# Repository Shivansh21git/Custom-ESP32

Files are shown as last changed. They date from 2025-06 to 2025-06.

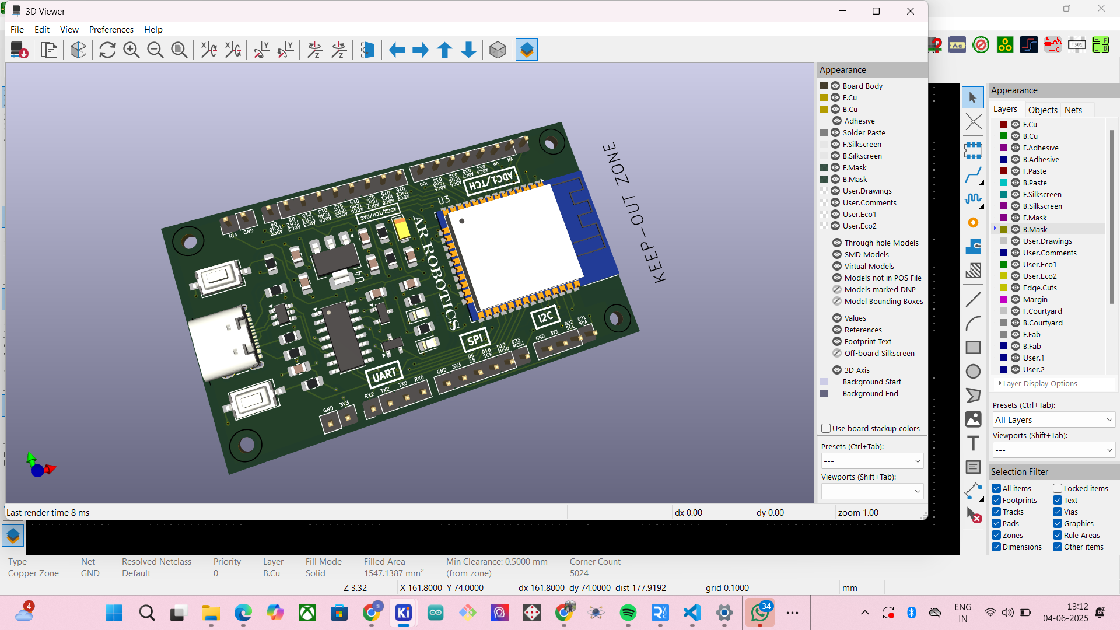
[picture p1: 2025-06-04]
Screenshot (103).png

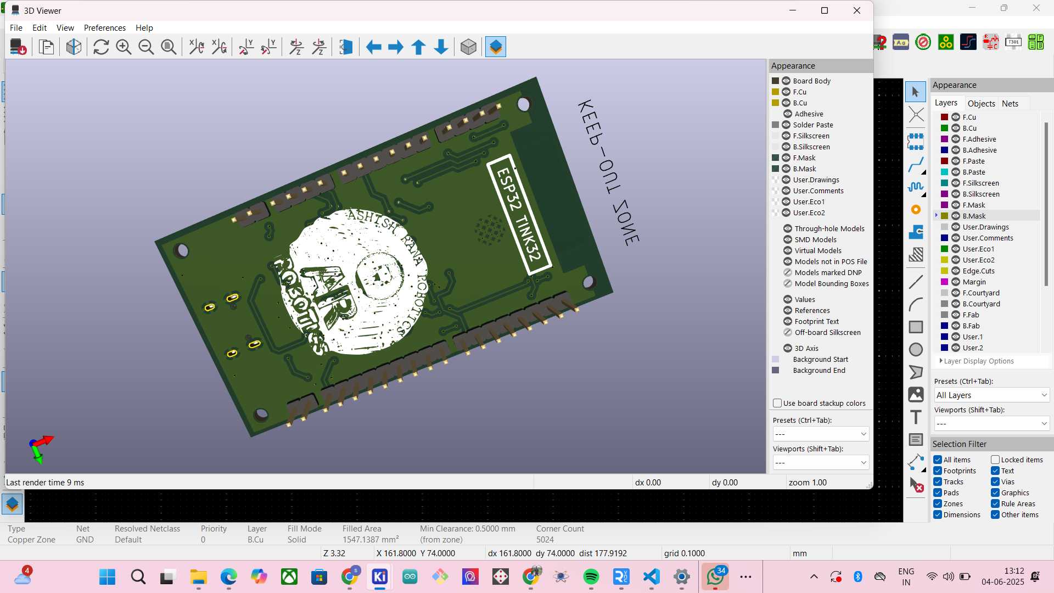
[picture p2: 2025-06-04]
Screenshot (104).png

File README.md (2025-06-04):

# 🚀 Custom ESP32 Development Board – Designed in KiCad

Welcome to the hardware design repo of a **fully custom ESP32-WROOM-32 development board**, engineered for rapid prototyping, compact integration, and modern embedded applications. Designed from the ground up using **KiCad**, this board blends functionality, minimalism, and scalability in one neat package.

---

## ✨ Key Features

- 🔌 **USB Type-C** interface with ESD protection and auto-reset
- 📡 **ESP32-WROOM-32** SoC (Wi-Fi + BLE, dual-core MCU)
- 🔋 **Onboard 3.3V LDO** regulator for stable low-noise operation
- 🎛️ **Accessible I/O headers**: UART, SPI, I2C, ADC, DAC, and GPIOs
- 📐 **Compact PCB layout** – Breadboard compatible
- 🛡️ **Proper antenna clearance & keep-out zone**
- 💾 Designed 100% in **KiCad 7.x**

---

## 🧠 Technical Overview

| Component | Details |
|---|---|
| **MCU** | ESP32-WROOM-32 (ESP32-D0WDQ6) |
| **USB Interface**| USB-C (via CH340/CP2102 + reset circuit) |
| **Power Input**  | 5V via USB-C |
| **Voltage Reg.** | AP2112 / AMS1117-3.3 LDO Regulator |
| **Reset Circuit**| BOOT & EN push buttons with RC logic |
| **Connectivity** | UART, I2C, SPI, ADC, DAC, PWM exposed |
| **Mounting** | 2x M2 screw holes for enclosure compatibility |
| **Board Size** | ~74mm x 32mm |

---

---

## 🛠️ Getting Started

### 🖥️ Open Project
- Clone this repo and open `custom_esp32.kicad_pro` in **KiCad 7.x**

### 🧾 Generate Gerbers
- Go to **File → Plot** → Generate files for your PCB manufacturer

### 🔧 Program the Board
- Use Arduino IDE / ESP-IDF
- Connect via USB-C
- Use `BOOT` + `EN` buttons for flashing if needed

---

## 📦 Fabrication Tips

- Board designed with **antenna clearance**
- Clean **silkscreen labeling** for easy assembly
- No component under USB port for low-profile casing
- Test points can be added if needed for production

---

## 💡 Applications

- IoT Device Development
- Sensor Gateway Nodes
- Home Automation
- Robotics Controller
- Custom Wireless Modules

---

## 🤝 Credits & Contact

Designed by **Shivansh Chauhan**  
📧 Email: `shivanshchauhan.228@gmail.com`  
🔗 LinkedIn: https://www.linkedin.com/in/shivanshchauhan2001

If you like this project, consider giving it a ⭐ on GitHub!

---

> “Great hardware begins with thoughtful design.”

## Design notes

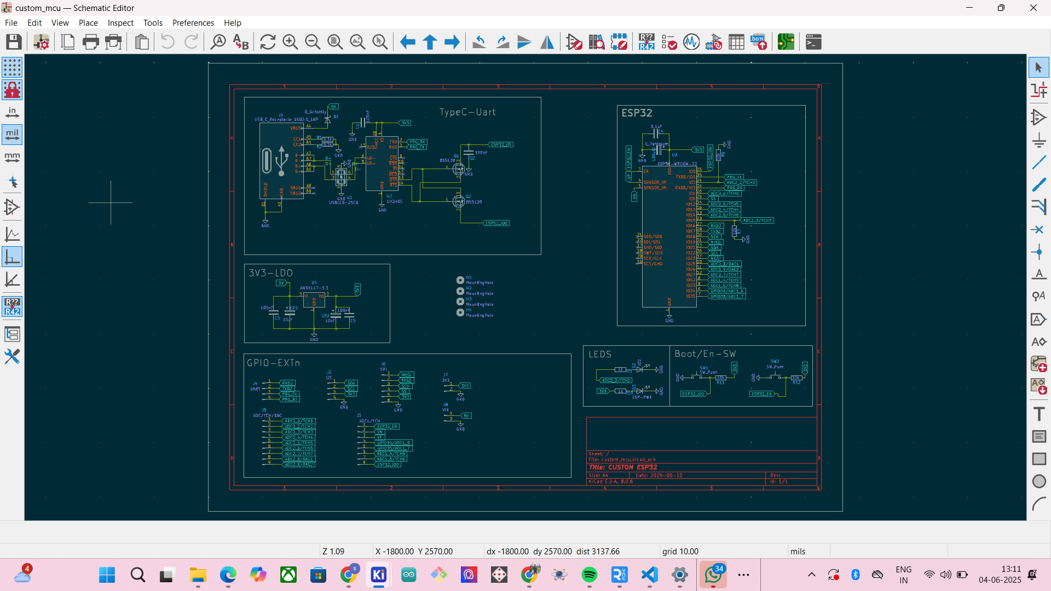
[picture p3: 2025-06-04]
Screenshot (100).png

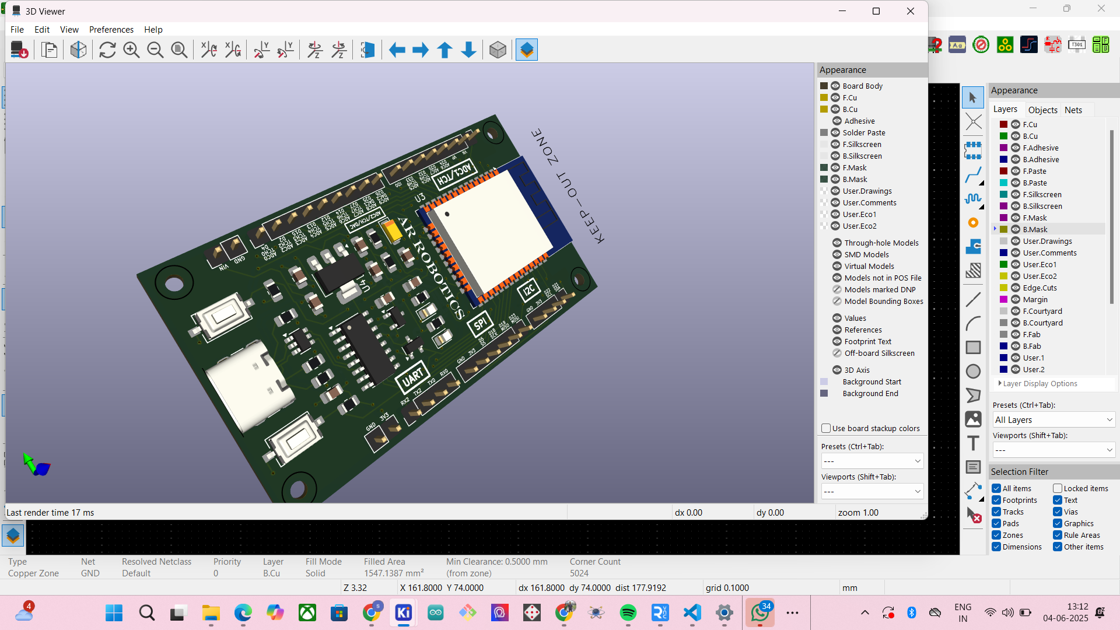
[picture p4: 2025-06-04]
Screenshot (105).png

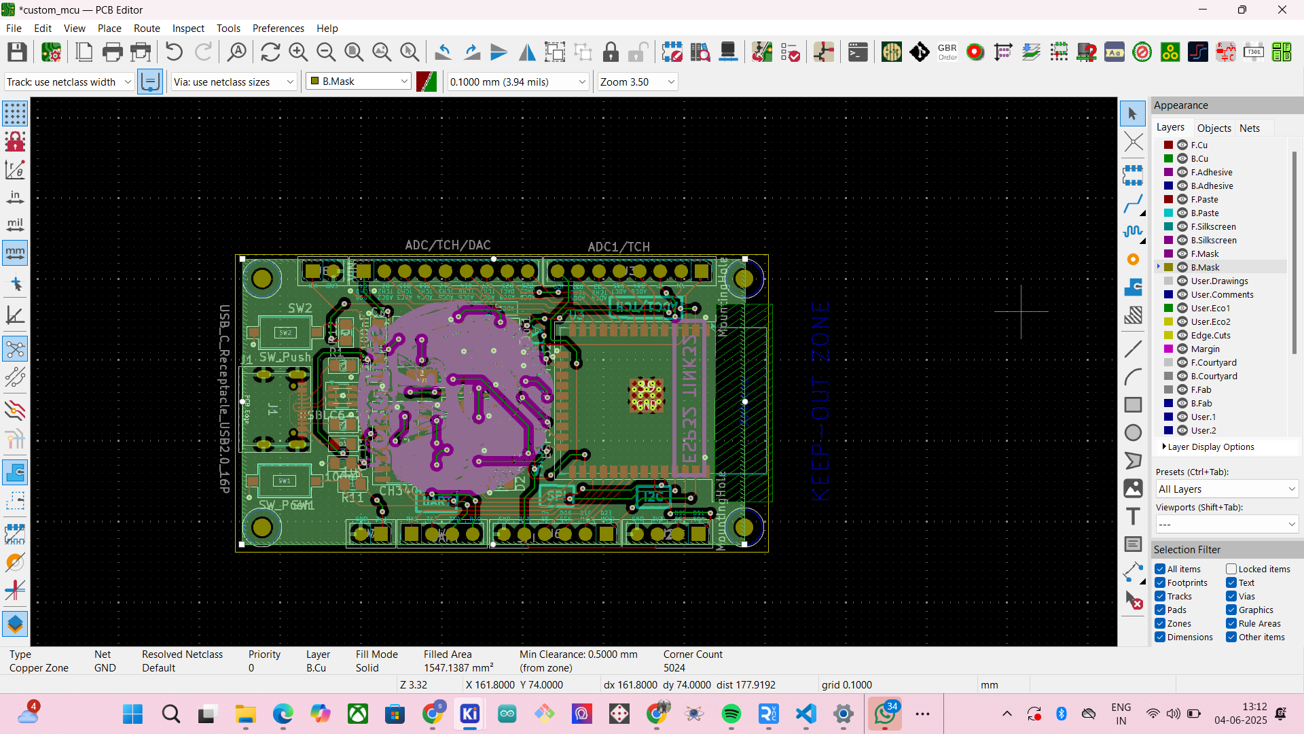
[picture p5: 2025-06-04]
Screenshot (102).png

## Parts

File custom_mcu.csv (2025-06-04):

Id | Designator | Footprint | Quantity | Designation | Supplier and ref
1 | C2,C2,C3,C1 | C_0805_2012Metric_Pad1.18x1.45mm_HandSolder | 4 | 100nF
2 | J4 | PinHeader_1x04_P2.54mm_Vertical | 1 | UART
3 | 100uf1 | CP_EIA-3216-10_Kemet-I | 1 | C_Tantalum
4 | Q2,Q1 | SOT-23 | 2 | BSS138
5 | J1 | USB_C_Receptacle_GCT_USB4105-xx-A_16P_TopMnt_Horizontal | 1 | USB_C_Receptacle_USB2.0_16P
6 | J5 | PinHeader_1x09_P2.54mm_Vertical | 1 | ADC/TCH/DAC
7 | R2,R1 | R_0805_2012Metric_Pad1.20x1.40mm_HandSolder | 2 | 5.1k
8 | C5 | C_0805_2012Metric_Pad1.18x1.45mm_HandSolder | 1 | 100nf
9 | CP1,CP2 | C_0805_2012Metric_Pad1.18x1.45mm_HandSolder | 2 | 10uf
10 | R11,R12,R6,R7 | R_0805_2012Metric_Pad1.20x1.40mm_HandSolder | 4 | 10k
11 | D2 | LED_0805_2012Metric_Pad1.15x1.40mm_HandSolder | 1 | IO2
12 | J7 | PinHeader_1x02_P2.54mm_Vertical | 1 | 3V3
13 | SW1,SW2 | SW_Tactile_SPST_NO_Straight_CK_PTS636Sx25SMTRLFS | 2 | SW_Push
14 | J2 | PinHeader_1x04_P2.54mm_Vertical | 1 | I2C
15 | D1 | R_0805_2012Metric_Pad1.20x1.40mm_HandSolder | 1 | D_Schottky
16 | U4 | SOT-223-3_TabPin2 | 1 | AMS1117-3.3
17 | U1 | SOT-23-6 | 1 | USBLC6-2SC6
18 | J6 | PinHeader_1x06_P2.54mm_Vertical | 1 | SPI
19 | U3 | ESP32-WROOM-32 | 1 | ESP32-WROOM-32
20 | J8 | PinHeader_1x02_P2.54mm_Vertical | 1 | VIN
21 | U2 | SOIC-16_3.9x9.9mm_P1.27mm | 1 | CH340C
22 | J3 | PinHeader_1x08_P2.54mm_Vertical | 1 | ADC1/TCH
23 | R10,R5 | R_0805_2012Metric_Pad1.20x1.40mm_HandSolder | 2 | 1k
24 | D3 | LED_0805_2012Metric_Pad1.15x1.40mm_HandSolder | 1 | ESP-PWR
25 | C4 | C_0805_2012Metric_Pad1.18x1.45mm_HandSolder | 1 | 0.1uF

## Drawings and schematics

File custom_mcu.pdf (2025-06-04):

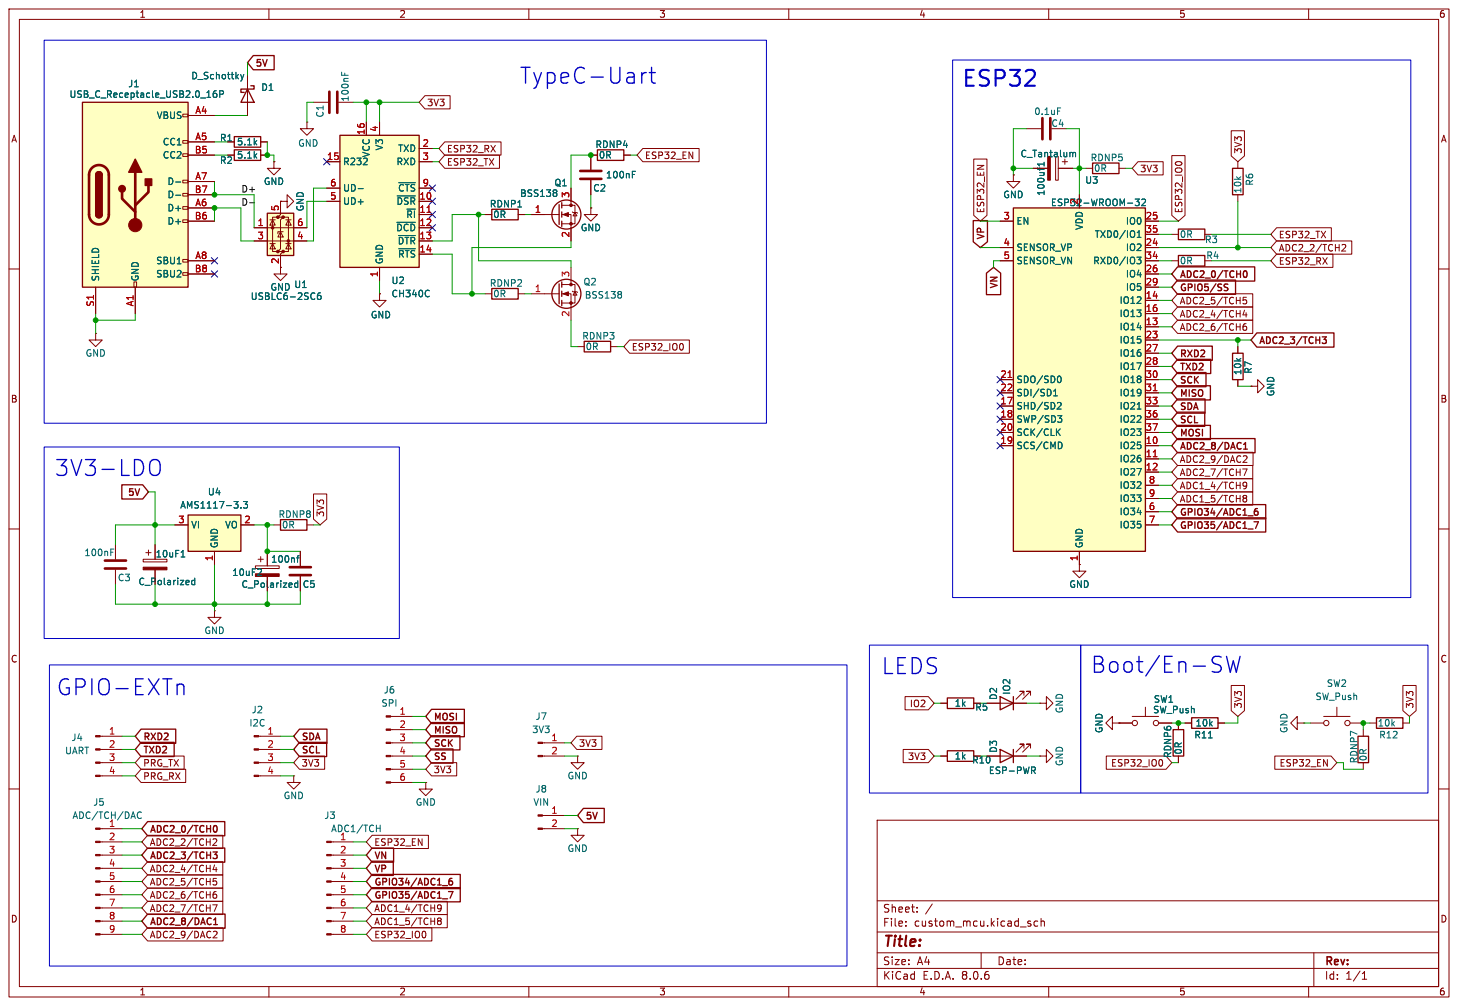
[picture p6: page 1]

1 ~{DSR} 10 ~{RI} 11 ~{DCD} 12 ~{DTR} 13 ~{RTS} 14 R232 15 VCC 16 TXD 2 RXD 3 V3

2 SCK/CLK 20 SDO/SD0 21 SDI/SD1 22

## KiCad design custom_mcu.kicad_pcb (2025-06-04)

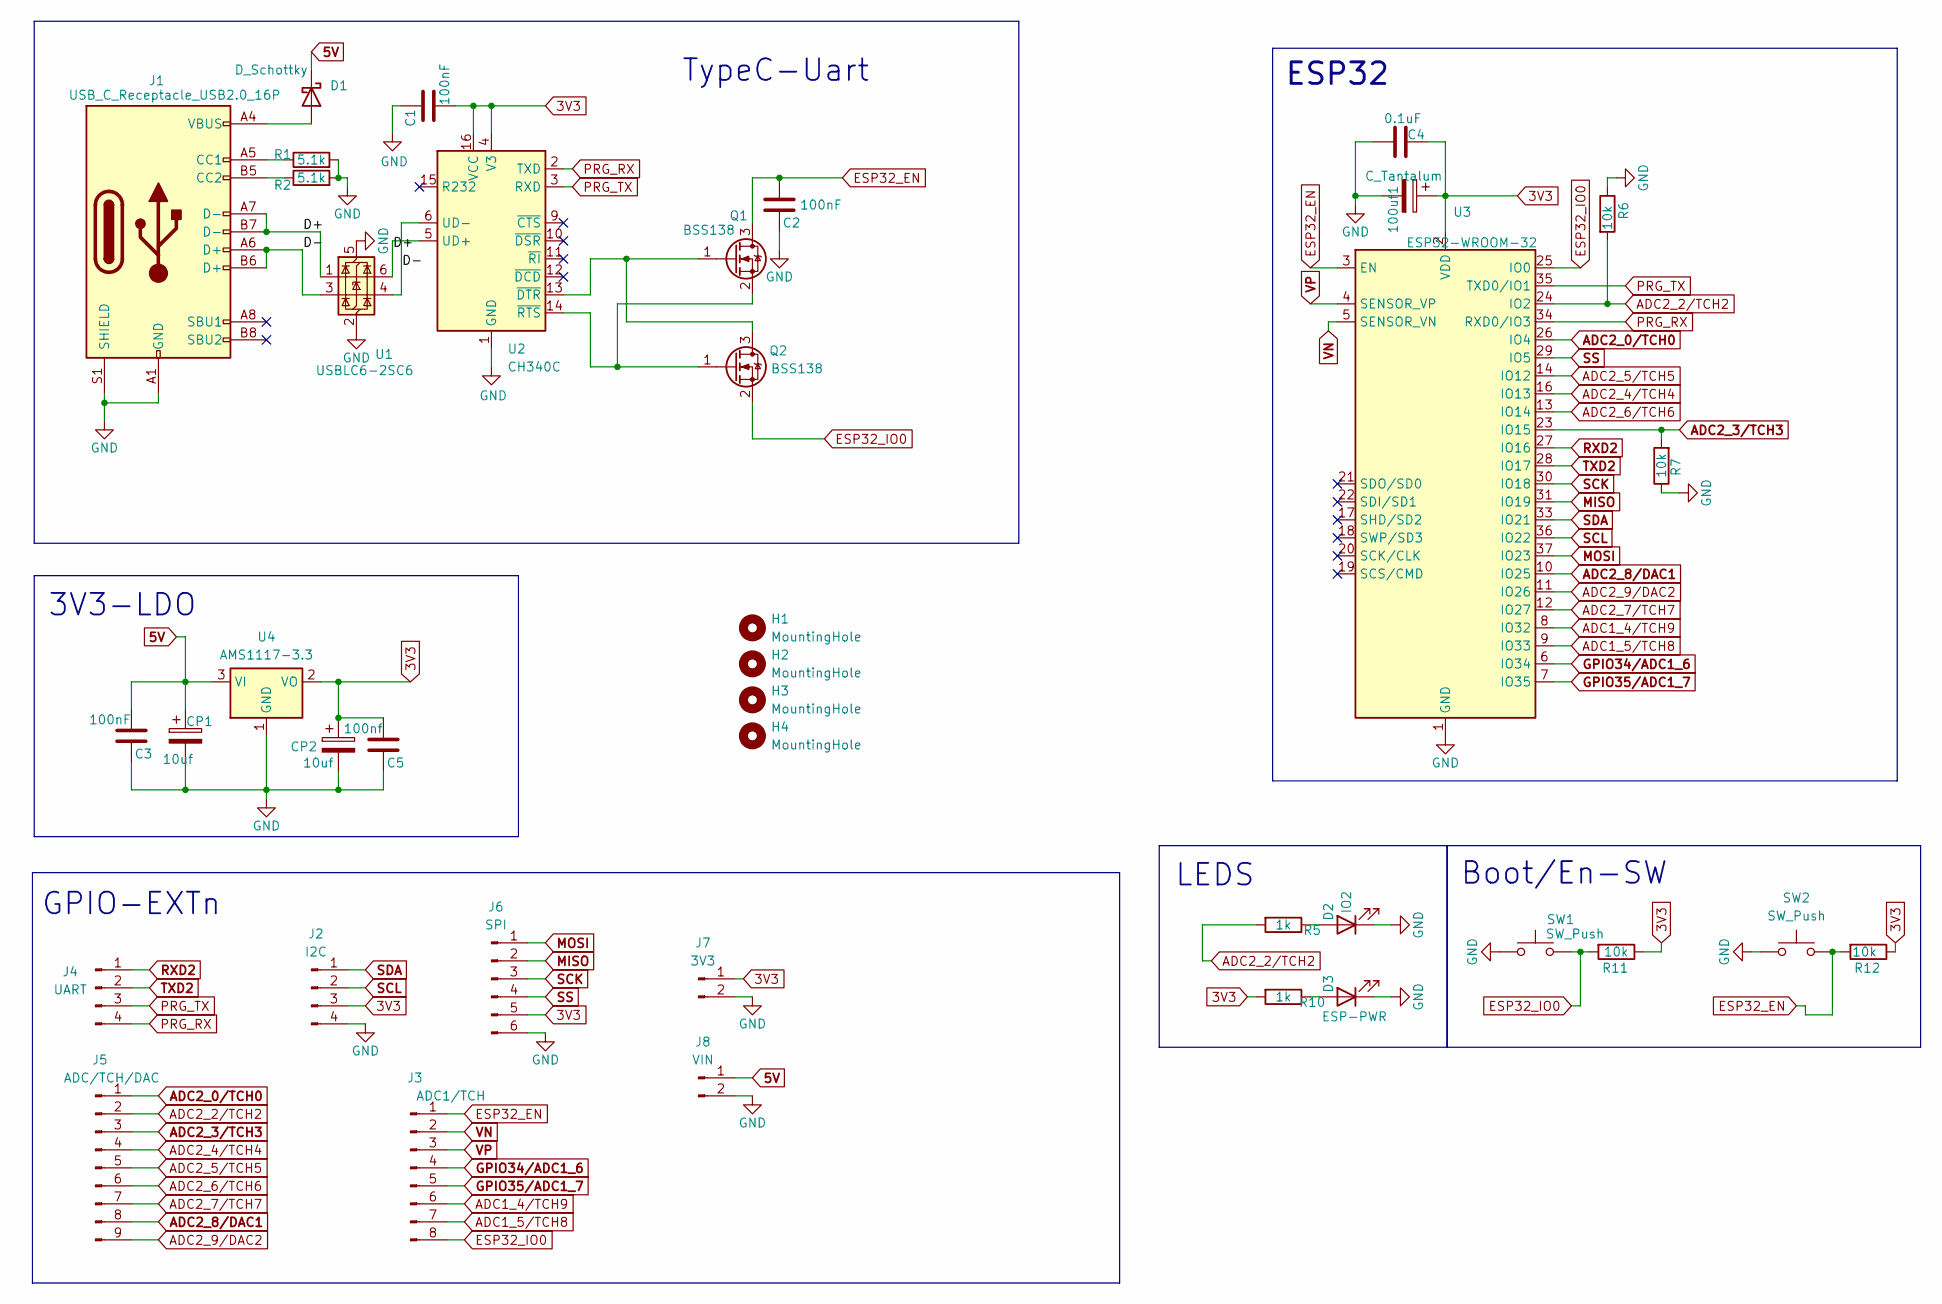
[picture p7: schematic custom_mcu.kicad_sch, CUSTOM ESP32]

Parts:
100uf1: C_Tantalum; CP_EIA-3216-10_Kemet-I
C1, C2, C3: 100nF; C_0805_2012Metric_Pad1.18x1.45mm_HandSolder
C4: 0.1uF; C_0805_2012Metric_Pad1.18x1.45mm_HandSolder
C5: 100nf; C_0805_2012Metric_Pad1.18x1.45mm_HandSolder
CP1, CP2: 10uf; C_0805_2012Metric_Pad1.18x1.45mm_HandSolder
D1: D_Schottky; R_0805_2012Metric_Pad1.20x1.40mm_HandSolder
D2: IO2; LED_0805_2012Metric_Pad1.15x1.40mm_HandSolder
D3: ESP-PWR; LED_0805_2012Metric_Pad1.15x1.40mm_HandSolder
H1, H2, H3, H4: MountingHole; MountingHole_2.2mm_M2
J1: USB_C_Receptacle_USB2.0_16P; USB_C_Receptacle_GCT_USB4105-xx-A_16P_TopMnt_Horizontal
J2: I2C; PinHeader_1x04_P2.54mm_Vertical
J3: ADC1/TCH; PinHeader_1x08_P2.54mm_Vertical
J4: UART; PinHeader_1x04_P2.54mm_Vertical
J5: ADC/TCH/DAC; PinHeader_1x09_P2.54mm_Vertical
J6: SPI; PinHeader_1x06_P2.54mm_Vertical
J7: 3V3; PinHeader_1x02_P2.54mm_Vertical
J8: VIN; PinHeader_1x02_P2.54mm_Vertical
Q1, Q2: BSS138; SOT-23
R1, R2: 5.1k; R_0805_2012Metric_Pad1.20x1.40mm_HandSolder
R5, R10: 1k; R_0805_2012Metric_Pad1.20x1.40mm_HandSolder
R6, R7, R11, R12: 10k; R_0805_2012Metric_Pad1.20x1.40mm_HandSolder
SW1, SW2: SW_Push; SW_Tactile_SPST_NO_Straight_CK_PTS636Sx25SMTRLFS
U1: USBLC6-2SC6; SOT-23-6
U2: CH340C; SOIC-16_3.9x9.9mm_P1.27mm
U3: ESP32-WROOM-32
U4: AMS1117-3.3; SOT-223-3_TabPin2

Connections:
3V3: 100uf1.1, C1.2, C4.2, C5.2, CP2.1, J2.3, J6.5, J7.1, R10.2, R11.1, R12.1, U2.4 (V3), U2.16 (VCC), U3.2 (VDD), U4.2 (VO)
5V: C3.2, CP1.1, D1.1 (K), J8.1, U4.3 (VI)
/D+: J1.A7 (D-), J1.B7 (D-), U1.1 (I/O1), U1.6 (I/O1), U2.5 (UD+)
/D-: J1.A6 (D+), J1.B6 (D+), U1.3 (I/O2), U1.4 (I/O2), U2.6 (UD-)
ADC1_4/TCH9: J3.6, U3.8 (IO32)
ADC1_5/TCH8: J3.7, U3.9 (IO33)
ADC2_0/TCH0: J5.1, U3.26 (IO4)
ADC2_2/TCH2: J5.2, R5.2, R6.2, U3.24 (IO2)
ADC2_3/TCH3: J5.3, R7.2, U3.23 (IO15)
ADC2_4/TCH4: J5.4, U3.16 (IO13)
ADC2_5/TCH5: J5.5, U3.14 (IO12)
ADC2_6/TCH6: J5.6, U3.13 (IO14)
ADC2_7/TCH7: J5.7, U3.12 (IO27)
ADC2_8/DAC1: J5.8, U3.10 (IO25)
ADC2_9/DAC2: J5.9, U3.11 (IO26)
ESP32_EN: C2.2, J3.1, Q1.3 (D), R12.2, SW2.2, U3.3 (EN); also elsewhere on the board
ESP32_IO0: J3.8, Q2.2 (S), R11.2, SW1.2, U3.25 (IO0)
GND: 100uf1.2, C1.1, C2.1, C3.1, C4.1, C5.1, CP1.2, CP2.2, D2.1 (K), D3.1 (K), J1.A1 (GND), J1.A12 (GND), J1.B1 (GND), J1.B12 (GND), J1.S1 (SHIELD), J2.4, J6.6, J7.2, J8.2, R1.2, R2.2, R6.1, R7.1, SW1.1, SW2.1, U1.2 (GND), U1.5 (VBUS), U2.1 (GND), U3.1 (GND), U3.15 (GND), U3.38 (GND), U3.39 (GND), U4.1 (GND); also elsewhere on the board
GPIO34/ADC1_6: J3.4, U3.6 (IO34)
GPIO35/ADC1_7: J3.5, U3.7 (IO35)
MISO: J6.2, U3.31 (IO19)
MOSI: J6.1, U3.37 (IO23)
unnamed: D1.2 (A), J1.A4 (VBUS), J1.A9 (VBUS), J1.B4 (VBUS), J1.B9 (VBUS)
unnamed: D2.2 (A), R5.1
unnamed: D3.2 (A), R10.1
unnamed: J1.A5 (CC1), R1.1
unnamed: J1.B5 (CC2), R2.1
unnamed: Q1.1 (G), Q2.3 (D), U2.13 (~DTR)
unnamed: Q1.2 (S), Q2.1 (G), U2.14 (~RTS)
PRG_RX: J4.4, U2.2 (TXD), U3.34 (RXD0/IO3)
PRG_TX: J4.3, U2.3 (RXD), U3.35 (TXD0/IO1)
RXD2: J4.1, U3.27 (IO16)
SCK: J6.3, U3.30 (IO18)
SCL: J2.2, U3.36 (IO22)
SDA: J2.1, U3.33 (IO21)
SS: J6.4, U3.29 (IO5)
TXD2: J4.2, U3.28 (IO17)
VN: J3.2, U3.5 (SENSOR_VN)
VP: J3.3, U3.4 (SENSOR_VP)

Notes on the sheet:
Boot/En-SW
GPIO-EXTn
3V3-LDO
TypeC-Uart
LEDS
ESP32

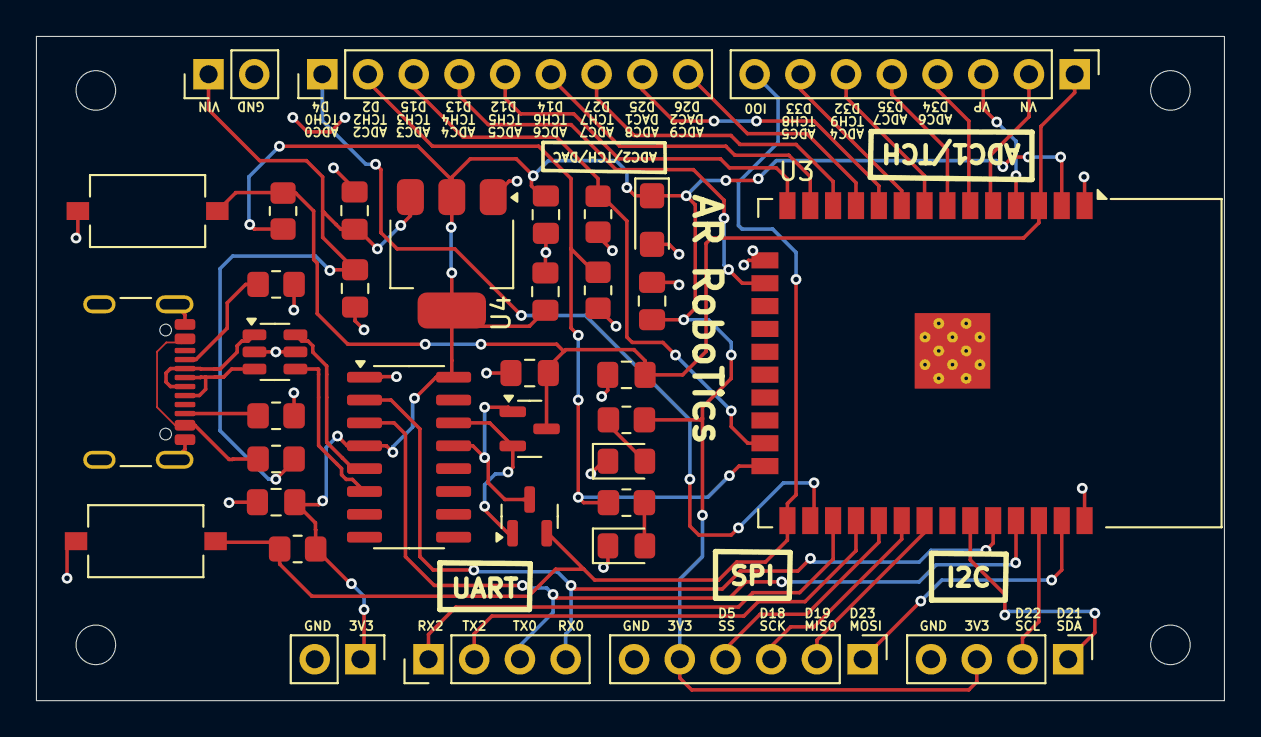
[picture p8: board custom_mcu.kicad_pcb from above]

Board: 2 copper layers, 66.0 x 36.9 mm, 40 parts (0 on the bottom side), 39 nets.

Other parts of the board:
C2#2: 100nF; C_0805_2012Metric_Pad1.18x1.45mm_HandSolder

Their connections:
ESP32_EN: C2#2.2; also elsewhere on the board
GND: C2#2.1; also elsewhere on the board
